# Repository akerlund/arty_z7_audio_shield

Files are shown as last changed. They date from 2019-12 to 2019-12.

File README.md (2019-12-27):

# arty_z7_audio_shield

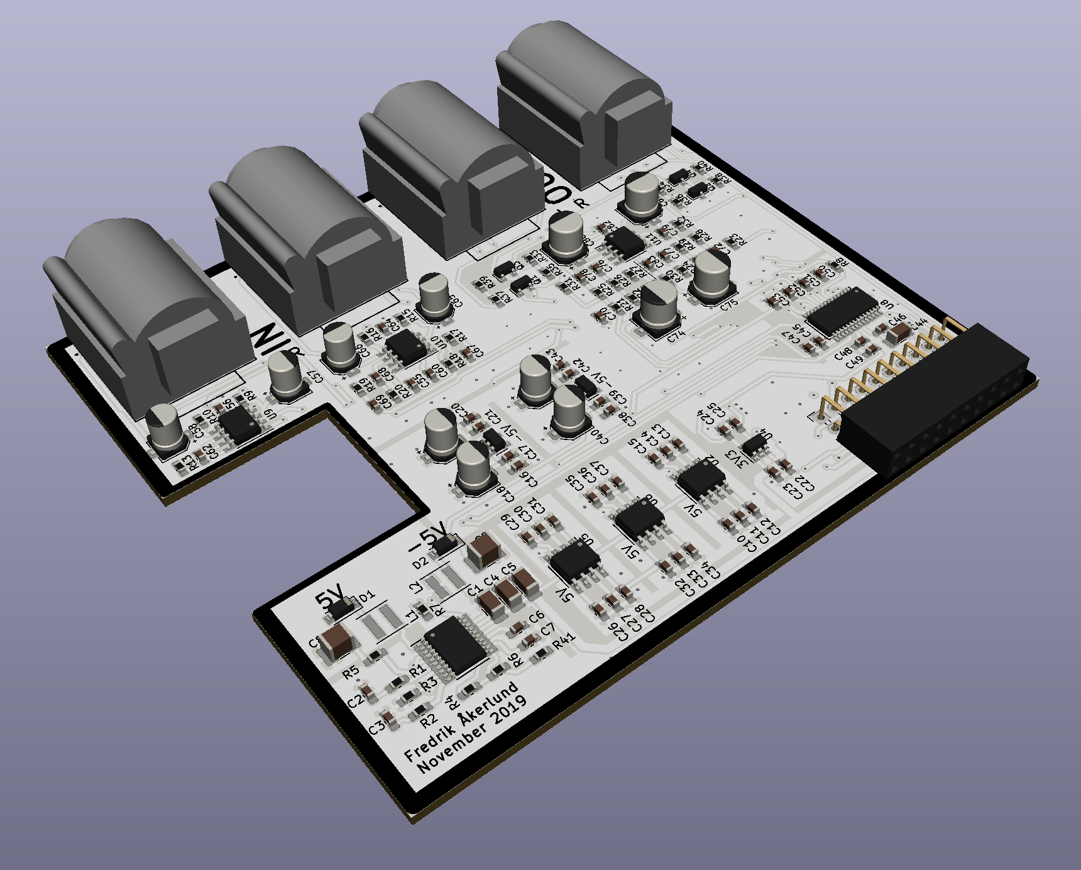
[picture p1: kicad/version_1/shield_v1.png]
The Shield


Stereo audio IF with a Cirrus CS4272 24-bit codec IC.
Designed to be placed as a shield on the Arty Z7 FPGA board.
Has a 20-pin connector for the "mixer interface", i.e., a PCB with sliders and encoders.

First test (verison1) failed, the +-5V booster (bottom left in pic) operates incorrecty and
eats a lot of current, causing the 3.3V supply down to 0.8V.

Forgot the exposed thermal pad under that IC, too. Fixed with some copper tape, but might correlate?

Next step is to try a new design, i.e., another booster.

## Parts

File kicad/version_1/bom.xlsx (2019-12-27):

Ref | Qnty |  | Value | Part | Footprint | Description | Vendor
C1, C4 | 2 |  | 3.3uF | Device:C | Capacitor_SMD:C_0603_1608Metric_Pad1.05x0.95mm_HandSolder | Unpolarized capacitor
C2, C3 | 2 |  | 47nF | Device:C | Capacitor_SMD:C_0603_1608Metric_Pad1.05x0.95mm_HandSolder | Unpolarized capacitor
C5 | 1 |  | 5.6uF | Device:C | Capacitor_SMD:C_0603_1608Metric_Pad1.05x0.95mm_HandSolder | Unpolarized capacitor
C6, C7, C11, C14, C22, C24, C25, C27, C30, C33, C36, C45, C47, C48, C50, C53 | 16 |  | 1uF | Device:C | Capacitor_SMD:C_0603_1608Metric_Pad1.05x0.95mm_HandSolder | Unpolarized capacitor
C8, C9 | 2 |  | 10uF | Device:C | Capacitor_SMD:C_1210_3225Metric_Pad1.42x2.65mm_HandSolder | Unpolarized capacitor
C10, C13, C16, C21, C23, C26, C29, C32, C35, C38, C43 | 11 |  | 100nF | Device:C | Capacitor_SMD:C_0603_1608Metric_Pad1.05x0.95mm_HandSolder | Unpolarized capacitor
C12, C15, C28, C31, C34, C37 | 6 |  | 2.2uF | Device:C | Capacitor_SMD:C_0603_1608Metric_Pad1.05x0.95mm_HandSolder | Unpolarized capacitor
C17, C20, C39, C42 | 4 |  | 1nF | Device:C | Capacitor_SMD:C_0603_1608Metric_Pad1.05x0.95mm_HandSolder | Unpolarized capacitor
C18, C19, C40, C41 | 4 |  | 2.2uF | Device:CP_Small | Capacitor_SMD:CP_Elec_4x5.7 | Polarized capacitor, small symbol
C44 | 1 |  | 47uF | Device:C | Capacitor_SMD:C_1206_3216Metric_Pad1.42x1.75mm_HandSolder | Unpolarized capacitor
C46, C49, C51, C52 | 4 |  | 0.1uF | Device:C | Capacitor_SMD:C_0603_1608Metric_Pad1.05x0.95mm_HandSolder | Unpolarized capacitor
C54, C55, C59, C60, C82, C83 | 6 |  | 2.2uF | Device:C | Capacitor_SMD:C_0603_1608Metric_Pad1.05x0.95mm_HandSolder | Unpolarized capacitor
C56, C64 | 2 | C0G | 0.01uF | Device:C | Capacitor_SMD:C_0603_1608Metric_Pad1.05x0.95mm_HandSolder | Unpolarized capacitor
C57, C58, C65, C66 | 4 |  | 10uF | Device:CP_Small | Capacitor_SMD:CP_Elec_4x5.7 | Polarized capacitor, small symbol
C61, C62, C67, C68, C78, C79 | 6 | C0G | 470pF | Device:C | Capacitor_SMD:C_0603_1608Metric_Pad1.05x0.95mm_HandSolder | Unpolarized capacitor
C63, C69 | 2 | C0G | 2.7nF | Device:C | Capacitor_SMD:C_0603_1608Metric_Pad1.05x0.95mm_HandSolder | Unpolarized capacitor
C70, C72 | 2 | C0G | 2.2nF | Device:C | Capacitor_SMD:C_0603_1608Metric_Pad1.05x0.95mm_HandSolder | Unpolarized capacitor
C71, C73 | 2 | C0G | 6.8nF | Device:C | Capacitor_SMD:C_0603_1608Metric_Pad1.05x0.95mm_HandSolder | Unpolarized capacitor
C74, C75 | 2 |  | 22uF | Device:C | Capacitor_SMD:CP_Elec_5x5.7 | Unpolarized capacitor
C76, C77 | 2 | C0G | 1.5nF | Device:C | Capacitor_SMD:C_0603_1608Metric_Pad1.05x0.95mm_HandSolder | Unpolarized capacitor
C80, C81 | 2 |  | 22uF | Device:CP_Small | Capacitor_SMD:CP_Elec_5x5.7 | Polarized capacitor, small symbol
D1, D2 | 2 |  | SCH | Device:D_Schottky | Diode_SMD:D_SOD-123 | Schottky diode
J1 | 1 |  | Conn_02x10_Odd_Even | Connector_Generic:Conn_02x10_Odd_Even | Connector_PinSocket_2.54mm:PinSocket_2x10_P2.54mm_Horizontal | Generic connector, double row, 02x10, odd/even pin numbering scheme (row 1 odd numbers, row 2 even numbers), script generated (kicad-library-utils/schlib/autogen/connector/)
J2 | 1 |  | IN_LEFT | SamacSys_Parts:NMJ4HCD2 | SamacSys_Parts:NMJ4HCD2 | Phone Connectors 2C MONO 2-SPST NC
J3 | 1 |  | OUT_LEFT | SamacSys_Parts:NMJ4HCD2 | SamacSys_Parts:NMJ4HCD2 | Phone Connectors 2C MONO 2-SPST NC
J4 | 1 |  | IN_RIGHT | SamacSys_Parts:NMJ4HCD2 | SamacSys_Parts:NMJ4HCD2 | Phone Connectors 2C MONO 2-SPST NC
J5 | 1 |  | OUT_RIGHT | SamacSys_Parts:NMJ4HCD2 | SamacSys_Parts:NMJ4HCD2 | Phone Connectors 2C MONO 2-SPST NC
L1 | 1 |  | 2.2uH | Device:L_Small | Inductor_SMD:L_Coilcraft_XxL4020 | Inductor, small symbol
L2 | 1 |  | 3.3uH | Device:L_Small | Inductor_SMD:L_Coilcraft_XxL4030 | Inductor, small symbol
Q1, Q2, Q3, Q4 | 4 |  | PNP_BEC | Device:Q_PNP_BEC | Package_TO_SOT_SMD:SOT-23 | PNP transistor, base/emitter/collector
R1 | 1 |  | 4.7k | Device:R | Resistor_SMD:R_0603_1608Metric_Pad1.05x0.95mm_HandSolder | Resistor
R2 | 1 |  | 8.2k | Device:R | Resistor_SMD:R_0603_1608Metric_Pad1.05x0.95mm_HandSolder | Resistor
R3 | 1 |  | 268k | Device:R | Resistor_SMD:R_0603_1608Metric_Pad1.05x0.95mm_HandSolder | Resistor
R4 | 1 |  | 158k | Device:R | Resistor_SMD:R_0603_1608Metric_Pad1.05x0.95mm_HandSolder | Resistor
R5 | 1 |  | 604k | Device:R | Resistor_SMD:R_0603_1608Metric_Pad1.05x0.95mm_HandSolder | Resistor
R6 | 1 |  | 1.15M | Device:R | Resistor_SMD:R_0603_1608Metric_Pad1.05x0.95mm_HandSolder | Resistor
R7 | 1 |  | 115k | Device:R | Resistor_SMD:R_0603_1608Metric_Pad1.05x0.95mm_HandSolder | Resistor
R8, R35, R36 | 3 |  | 47k | Device:R | Resistor_SMD:R_0603_1608Metric_Pad1.05x0.95mm_HandSolder | Resistor
R9, R10, R15, R16, R37, R38 | 6 |  | 10k | Device:R | Resistor_SMD:R_0603_1608Metric_Pad1.05x0.95mm_HandSolder | Resistor
R11, R13, R17, R19 | 4 |  | 634R | Device:R | Resistor_SMD:R_0603_1608Metric_Pad1.05x0.95mm_HandSolder | Resistor
R12, R14, R18, R20 | 4 |  | 91R | Device:R | Resistor_SMD:R_0603_1608Metric_Pad1.05x0.95mm_HandSolder | Resistor
R21, R23 | 2 |  | 4.42k | Device:R | Resistor_SMD:R_0603_1608Metric_Pad1.05x0.95mm_HandSolder | Resistor
R22, R24 | 2 |  | 1.33k | Device:R | Resistor_SMD:R_0603_1608Metric_Pad1.05x0.95mm_HandSolder | Resistor
R25, R28 | 2 |  | 2.32k | Device:R | Resistor_SMD:R_0603_1608Metric_Pad1.05x0.95mm_HandSolder | Resistor
R26, R29 | 2 |  | 715R | Device:R | Resistor_SMD:R_0603_1608Metric_Pad1.05x0.95mm_HandSolder | Resistor
R27, R30 | 2 |  | 1.5k | Device:R | Resistor_SMD:R_0603_1608Metric_Pad1.05x0.95mm_HandSolder | Resistor
R31, R32 | 2 |  | 4.99k | Device:R | Resistor_SMD:R_0603_1608Metric_Pad1.05x0.95mm_HandSolder | Resistor
R33, R34 | 2 |  | 560R | Device:R | Resistor_SMD:R_0603_1608Metric_Pad1.05x0.95mm_HandSolder | Resistor
R39, R40 | 2 |  | 2k | Device:R | Resistor_SMD:R_0603_1608Metric_Pad1.05x0.95mm_HandSolder | Resistor
U1 | 1 |  | ADP5071 | freakuency:ADP5071 | Package_SO:TSSOP-20_4.4x6.5mm_P0.65mm
U2, U5, U6 | 3 |  | ADP7118 | freakuency:ADP7118 | Package_SO:SOIC-8_3.9x4.9mm_P1.27mm
U3, U7 | 2 |  | ADP7182 | freakuency:ADP7182 | Package_TO_SOT_SMD:SOT-23-5
U4 | 1 |  | MIC5211 | freakuency:MIC5211 | Package_TO_SOT_SMD:SOT-23-6
U8 | 1 |  | CS4272 | freakuency:CS4272 | Package_SO:TSSOP-28_4.4x9.7mm_P0.65mm
U9, U10, U11 | 3 |  | MC33078 | freakuency:MC33078 | Package_SO:SOIC-8_3.9x4.9mm_P1.27mm
U12 | 1 |  | chip_kit | freakuency:chip_kit | f_library:chipKIT

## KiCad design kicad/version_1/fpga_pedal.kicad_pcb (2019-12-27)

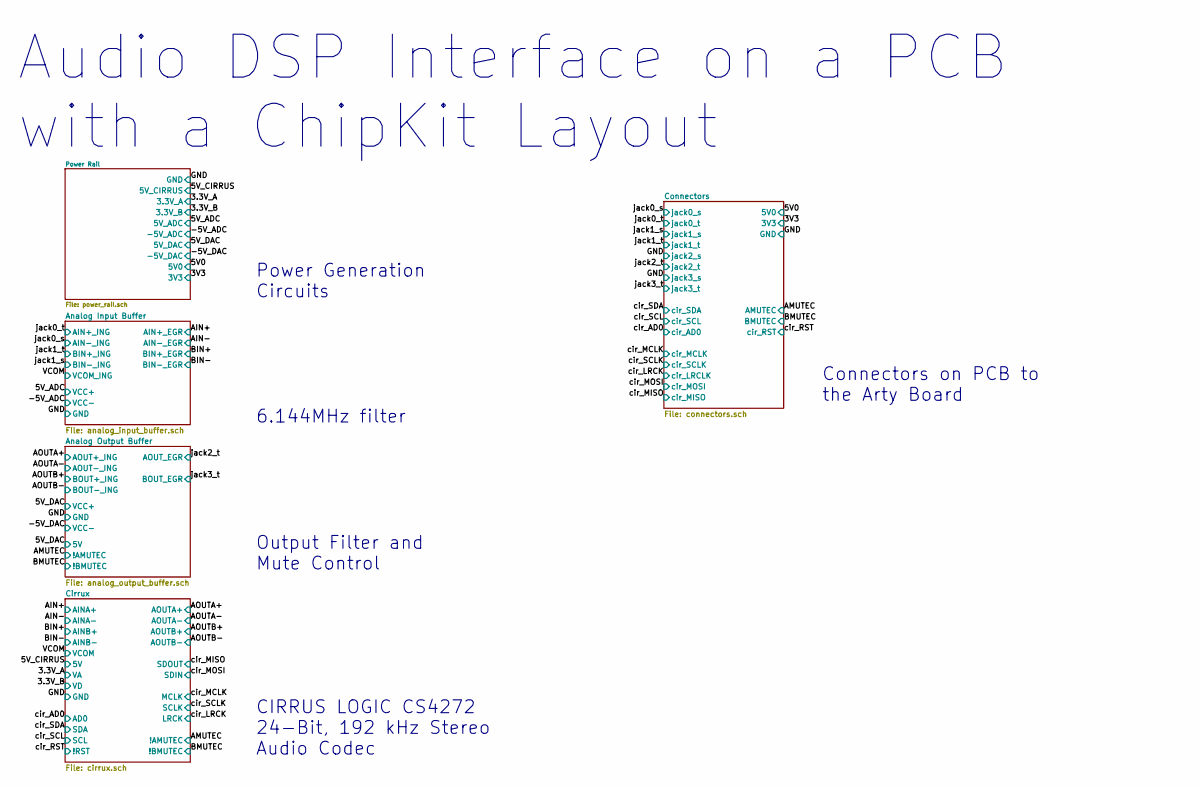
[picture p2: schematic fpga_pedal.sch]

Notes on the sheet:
CIRRUS LOGIC CS4272 24-Bit, 192 kHz Stereo Audio Codec
6.144MHz filter
Output Filter and Mute Control
Power Generation Circuits
Connectors on PCB to the Arty Board
Audio DSP Interface on a PCB with a ChipKit Layout

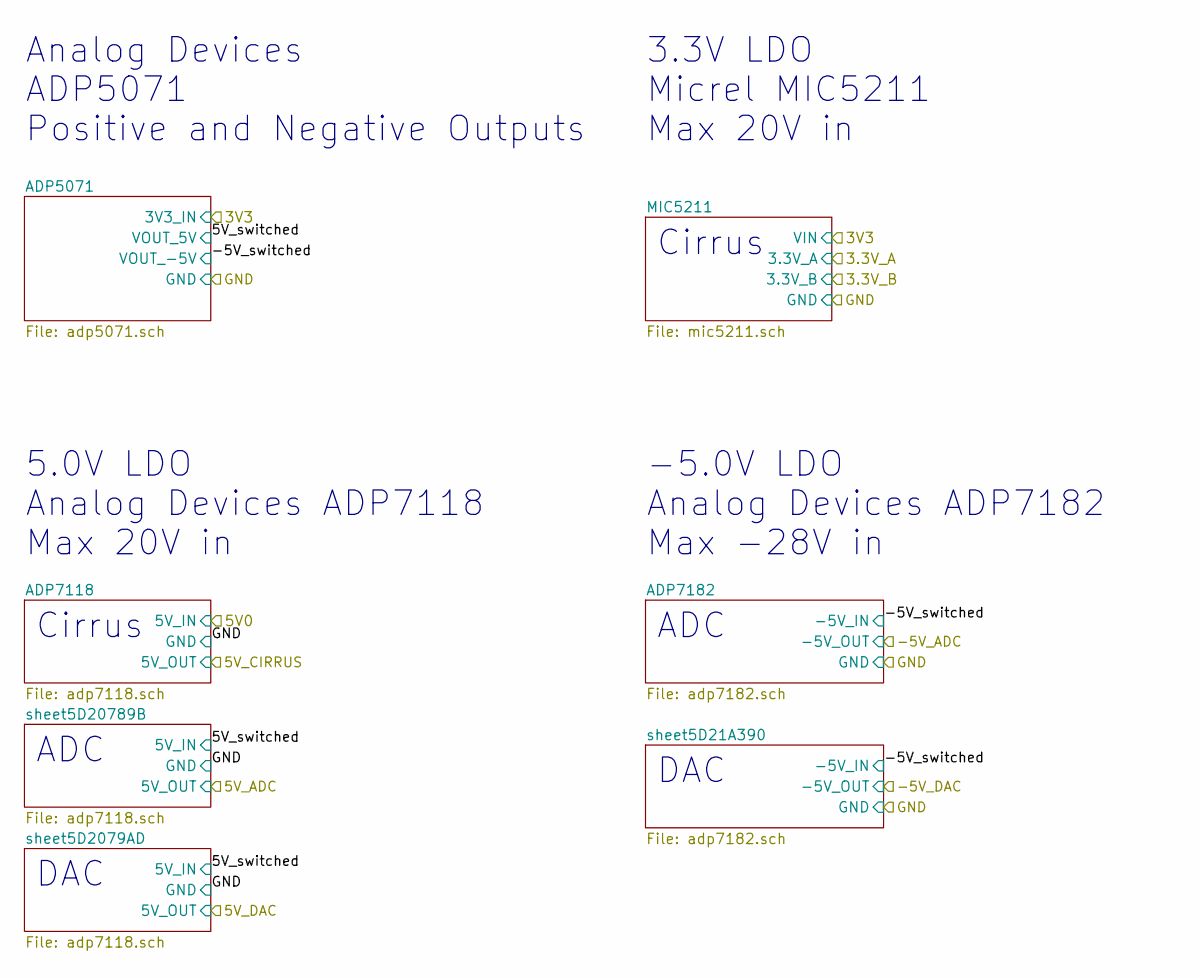
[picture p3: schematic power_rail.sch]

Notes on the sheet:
3.3V LDO Micrel MIC5211 Max 20V in
5.0V LDO Analog Devices ADP7118 Max 20V in
-5.0V LDO Analog Devices ADP7182 Max -28V in
Analog Devices ADP5071 Positive and Negative Outputs
ADC
Cirrus
DAC

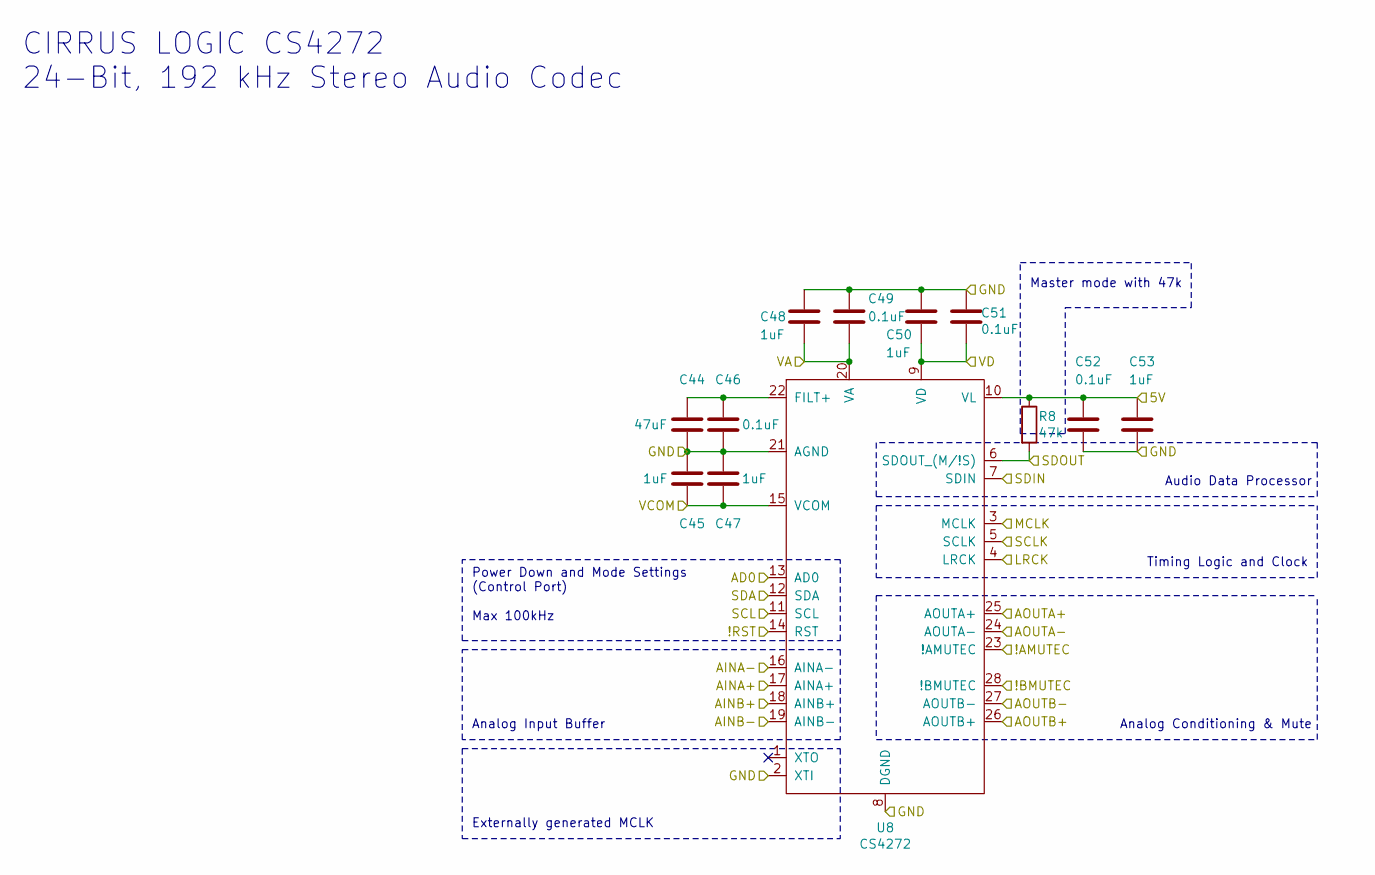
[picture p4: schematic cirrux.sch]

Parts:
C44: 47uF; C_1206_3216Metric_Pad1.42x1.75mm_HandSolder
C45, C47, C48, C50, C53: 1uF; C_0603_1608Metric_Pad1.05x0.95mm_HandSolder
C46, C49, C51, C52: 0.1uF; C_0603_1608Metric_Pad1.05x0.95mm_HandSolder
R8: 47k; R_0603_1608Metric_Pad1.05x0.95mm_HandSolder
U8: CS4272; TSSOP-28_4.4x9.7mm_P0.65mm

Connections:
/3.3V_A: C48.2, C49.2, U8.20 (VA); also elsewhere on the board
/3.3V_B: C50.2, C51.2, U8.9 (VD); also elsewhere on the board
/5V_CIRRUS: C52.1, C53.1, R8.1, U8.10 (VL); also elsewhere on the board
/AIN+: U8.17 (AINA+); also elsewhere on the board
/AIN-: U8.16 (AINA-); also elsewhere on the board
/AMUTEC: U8.23 (!AMUTEC); also elsewhere on the board
/AOUTA+: U8.25 (AOUTA+); also elsewhere on the board
/AOUTA-: U8.24 (AOUTA-); also elsewhere on the board
/AOUTB+: U8.26 (AOUTB+); also elsewhere on the board
/AOUTB-: U8.27 (AOUTB-); also elsewhere on the board
/BIN+: U8.18 (AINB+); also elsewhere on the board
/BIN-: U8.19 (AINB-); also elsewhere on the board
/BMUTEC: U8.28 (!BMUTEC); also elsewhere on the board
/GND: C44.2, C45.1, C46.2, C47.1, C48.1, C49.1, C50.1, C51.1, C52.2, C53.2, U8.2 (XTI), U8.8 (DGND), U8.21 (AGND); also elsewhere on the board
/VCOM: C45.2, C47.2, U8.15 (VCOM); also elsewhere on the board
/cir_AD0: U8.13 (AD0); also elsewhere on the board
/cir_LRCK: U8.4 (LRCK); also elsewhere on the board
/cir_MCLK: U8.3 (MCLK); also elsewhere on the board
/cir_MISO: R8.2, U8.6 (SDOUT_(M/!S)); also elsewhere on the board
/cir_MOSI: U8.7 (SDIN); also elsewhere on the board
/cir_RST: U8.14 (RST); also elsewhere on the board
/cir_SCL: U8.11 (SCL); also elsewhere on the board
/cir_SCLK: U8.5 (SCLK); also elsewhere on the board
/cir_SDA: U8.12 (SDA); also elsewhere on the board
unnamed: C44.1, C46.1, U8.22 (FILT+)

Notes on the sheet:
Analog Input Buffer
Power Down and Mode Settings (Control Port) Max 100kHz
Analog Conditioning & Mute
Timing Logic and Clock
Audio Data Processor
Master mode with 47k
Externally generated MCLK
CIRRUS LOGIC CS4272 24-Bit, 192 kHz Stereo Audio Codec

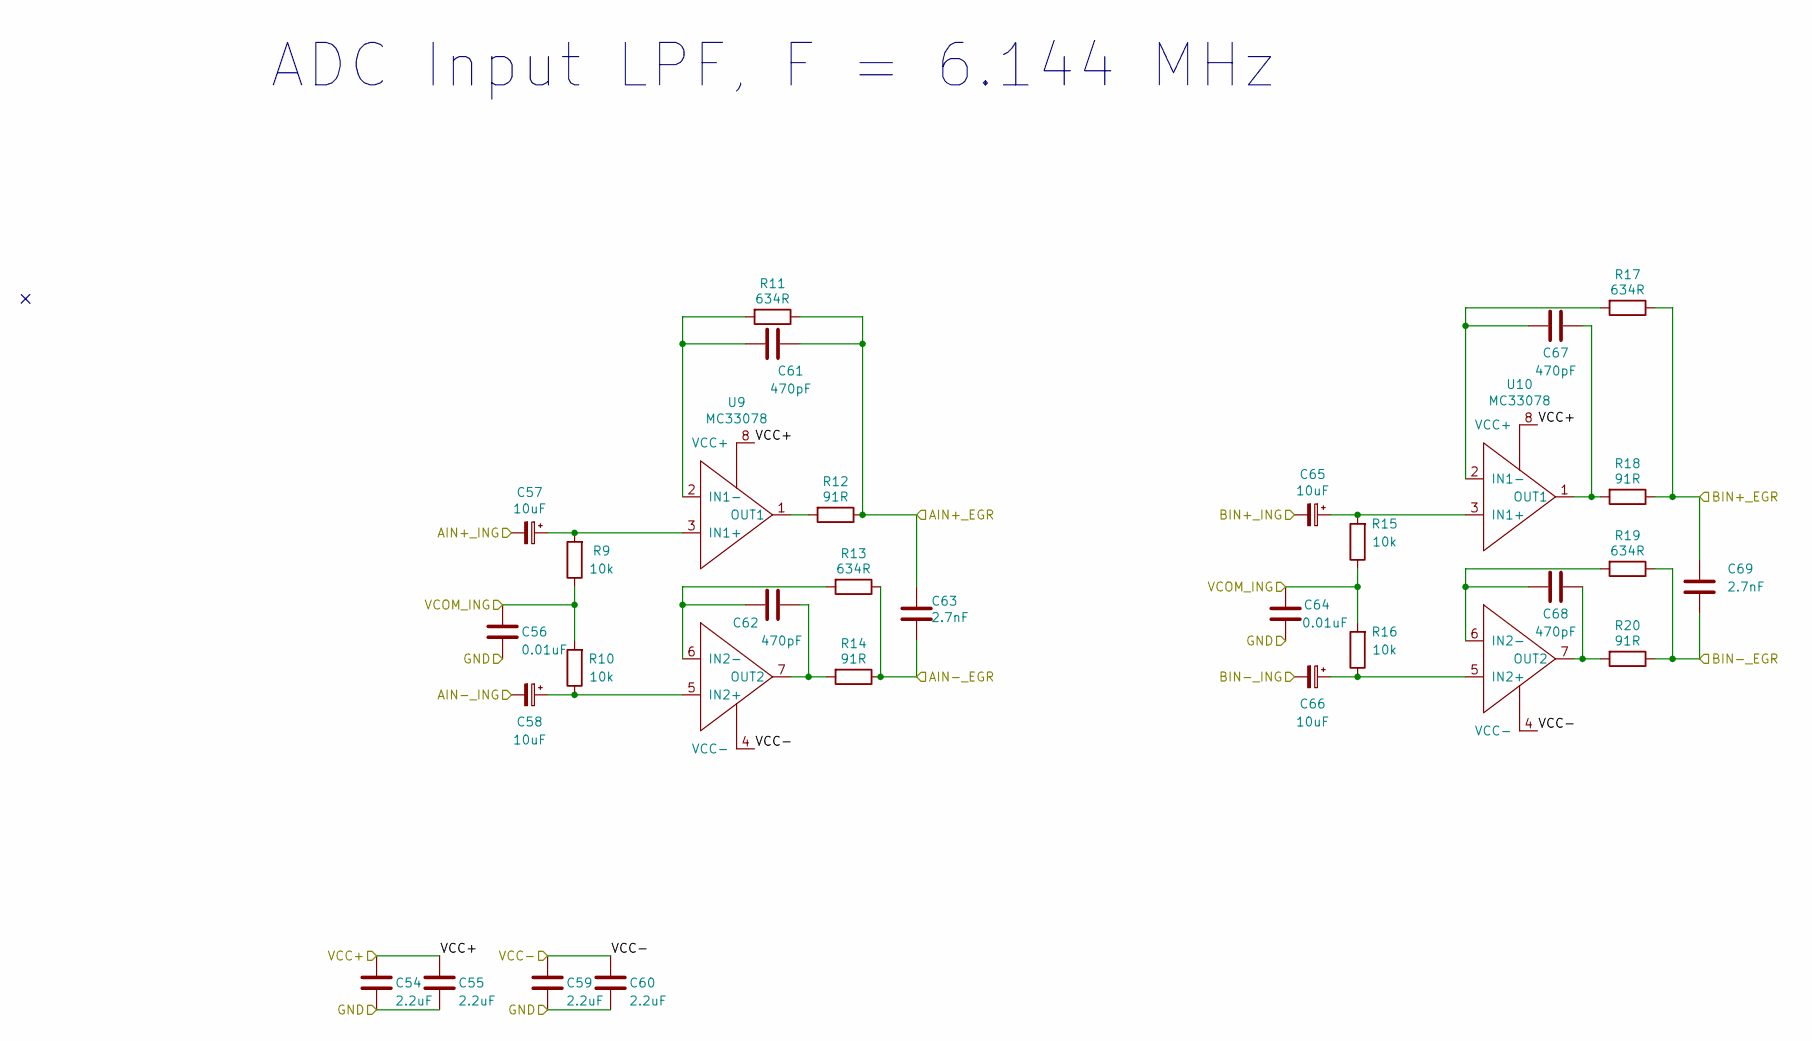
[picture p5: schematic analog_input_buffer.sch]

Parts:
C54, C55, C59, C60: 2.2uF; C_0603_1608Metric_Pad1.05x0.95mm_HandSolder
C56, C64: 0.01uF; C_0603_1608Metric_Pad1.05x0.95mm_HandSolder
C57, C58, C65, C66: 10uF; CP_Elec_4x5.7
C61, C62, C67, C68: 470pF; C_0603_1608Metric_Pad1.05x0.95mm_HandSolder
C63, C69: 2.7nF; C_0603_1608Metric_Pad1.05x0.95mm_HandSolder
R9, R10, R15, R16: 10k; R_0603_1608Metric_Pad1.05x0.95mm_HandSolder
R11, R13, R17, R19: 634R; R_0603_1608Metric_Pad1.05x0.95mm_HandSolder
R12, R14, R18, R20: 91R; R_0603_1608Metric_Pad1.05x0.95mm_HandSolder
U9, U10: MC33078; SOIC-8_3.9x4.9mm_P1.27mm

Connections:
/5V_ADC: C54.2, C55.2, U9.8 (VCC+), U10.8 (VCC+); also elsewhere on the board
/-5V_ADC: C59.2, C60.2, U9.4 (VCC-), U10.4 (VCC-); also elsewhere on the board
/AIN+: C61.1, C63.2, R11.1, R12.1; also elsewhere on the board
/AIN-: C63.1, R13.1, R14.1; also elsewhere on the board
/BIN+: C69.2, R17.1, R18.1; also elsewhere on the board
/BIN-: C69.1, R19.1, R20.1; also elsewhere on the board
/GND: C54.1, C55.1, C56.1, C59.1, C60.1, C64.1; also elsewhere on the board
/VCOM: C56.2, C64.2, R9.1, R10.2, R15.1, R16.2; also elsewhere on the board
/jack0_s: C58.2; also elsewhere on the board
/jack0_t: C57.2; also elsewhere on the board
/jack1_s: C66.2; also elsewhere on the board
/jack1_t: C65.2; also elsewhere on the board
unnamed: C57.1, R9.2, U9.3 (IN1+)
unnamed: C58.1, R10.1, U9.5 (IN2+)
unnamed: C61.2, R11.2, U9.2 (IN1-)
unnamed: C62.1, R14.2, U9.7 (OUT2)
unnamed: C62.2, R13.2, U9.6 (IN2-)
unnamed: C65.1, R15.2, U10.3 (IN1+)
unnamed: C66.1, R16.1, U10.5 (IN2+)
unnamed: C67.1, R18.2, U10.1 (OUT1)
unnamed: C67.2, R17.2, U10.2 (IN1-)
unnamed: C68.1, R20.2, U10.7 (OUT2)
unnamed: C68.2, R19.2, U10.6 (IN2-)
unnamed: R12.2, U9.1 (OUT1)

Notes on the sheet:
ADC Input LPF, F = 6.144 MHz

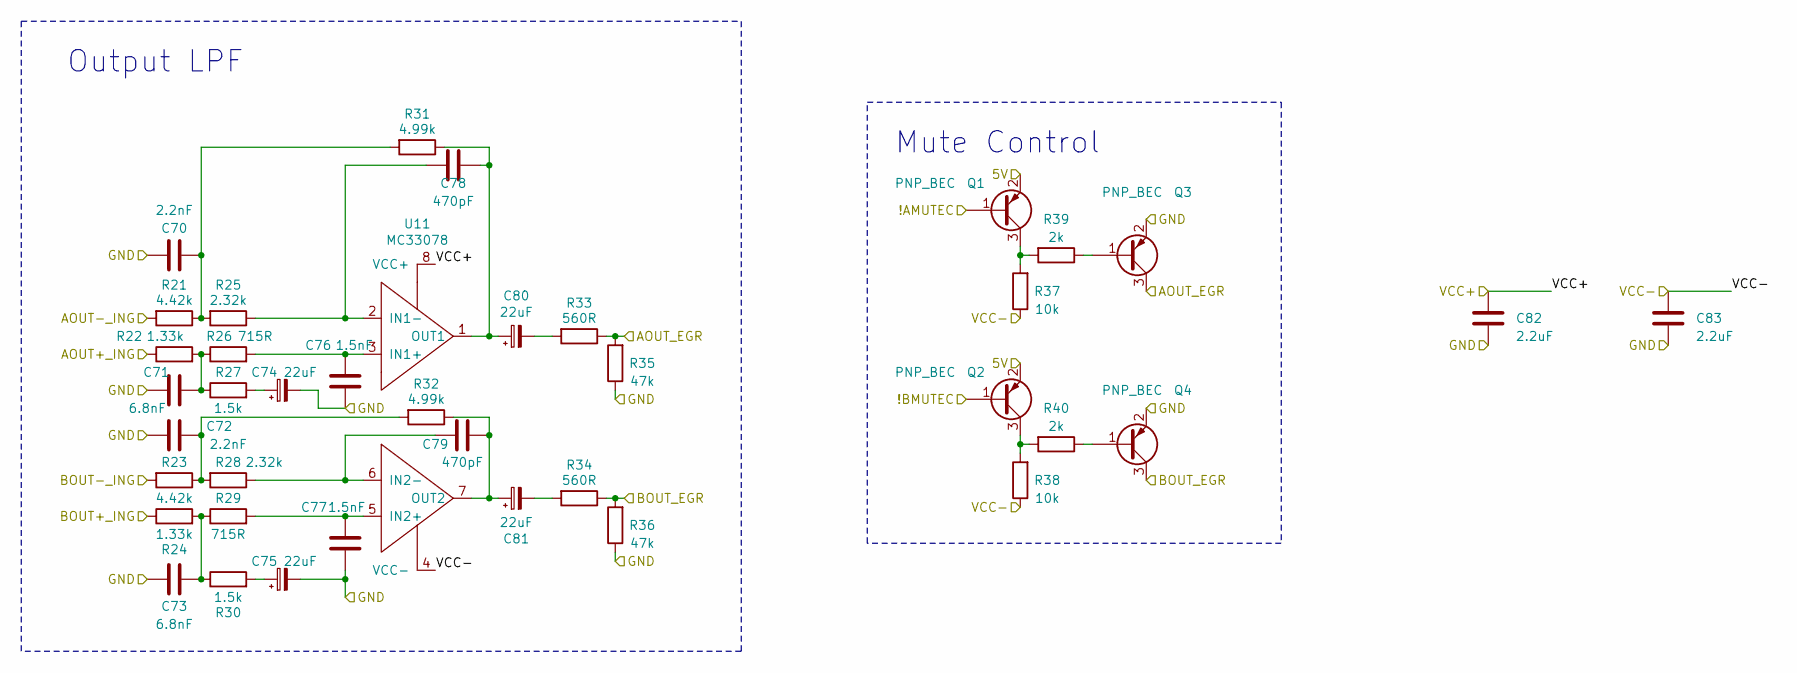
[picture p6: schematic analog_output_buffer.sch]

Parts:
C70, C72: 2.2nF; C_0603_1608Metric_Pad1.05x0.95mm_HandSolder
C71, C73: 6.8nF; C_0603_1608Metric_Pad1.05x0.95mm_HandSolder
C74, C75, C80, C81: 22uF; CP_Elec_5x5.7
C76, C77: 1.5nF; C_0603_1608Metric_Pad1.05x0.95mm_HandSolder
C78, C79: 470pF; C_0603_1608Metric_Pad1.05x0.95mm_HandSolder
C82, C83: 2.2uF; C_0603_1608Metric_Pad1.05x0.95mm_HandSolder
Q1, Q2, Q3, Q4: PNP_BEC; SOT-23
R21, R23: 4.42k; R_0603_1608Metric_Pad1.05x0.95mm_HandSolder
R22, R24: 1.33k; R_0603_1608Metric_Pad1.05x0.95mm_HandSolder
R25, R28: 2.32k; R_0603_1608Metric_Pad1.05x0.95mm_HandSolder
R26, R29: 715R; R_0603_1608Metric_Pad1.05x0.95mm_HandSolder
R27, R30: 1.5k; R_0603_1608Metric_Pad1.05x0.95mm_HandSolder
R31, R32: 4.99k; R_0603_1608Metric_Pad1.05x0.95mm_HandSolder
R33, R34: 560R; R_0603_1608Metric_Pad1.05x0.95mm_HandSolder
R35, R36: 47k; R_0603_1608Metric_Pad1.05x0.95mm_HandSolder
R37, R38: 10k; R_0603_1608Metric_Pad1.05x0.95mm_HandSolder
R39, R40: 2k; R_0603_1608Metric_Pad1.05x0.95mm_HandSolder
U11: MC33078; SOIC-8_3.9x4.9mm_P1.27mm

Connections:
/5V_DAC: C82.2, Q1.2 (E), Q2.2 (E), U11.8 (VCC+); also elsewhere on the board
/-5V_DAC: C83.2, R37.1, R38.1, U11.4 (VCC-); also elsewhere on the board
/AMUTEC: Q1.1 (B); also elsewhere on the board
/AOUTA+: R22.1; also elsewhere on the board
/AOUTA-: R21.2; also elsewhere on the board
/AOUTB+: R24.1; also elsewhere on the board
/AOUTB-: R23.2; also elsewhere on the board
/BMUTEC: Q2.1 (B); also elsewhere on the board
/GND: C70.1, C71.2, C72.1, C73.2, C74.2, C75.2, C76.2, C77.1, C82.1, C83.1, Q3.2 (E), Q4.2 (E), R35.1, R36.1; also elsewhere on the board
/jack2_t: Q3.3 (C), R33.1, R35.2; also elsewhere on the board
/jack3_t: Q4.3 (C), R34.1, R36.2; also elsewhere on the board
unnamed: C70.2, R21.1, R25.2, R31.2
unnamed: C71.1, R22.2, R26.1, R27.1
unnamed: C72.2, R23.1, R28.2, R32.2
unnamed: C73.1, R24.2, R29.1, R30.1
unnamed: C74.1, R27.2
unnamed: C75.1, R30.2
unnamed: C76.1, R26.2, U11.3 (IN1+)
unnamed: C77.2, R29.2, U11.5 (IN2+)
unnamed: C78.1, C80.1, R31.1, U11.1 (OUT1)
unnamed: C78.2, R25.1, U11.2 (IN1-)
unnamed: C79.1, C81.1, R32.1, U11.7 (OUT2)
unnamed: C79.2, R28.1, U11.6 (IN2-)
unnamed: C80.2, R33.2
unnamed: C81.2, R34.2
unnamed: Q1.3 (C), R37.2, R39.2
unnamed: Q2.3 (C), R38.2, R40.2
unnamed: Q3.1 (B), R39.1
unnamed: Q4.1 (B), R40.1

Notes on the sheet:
Mute Control
Output LPF

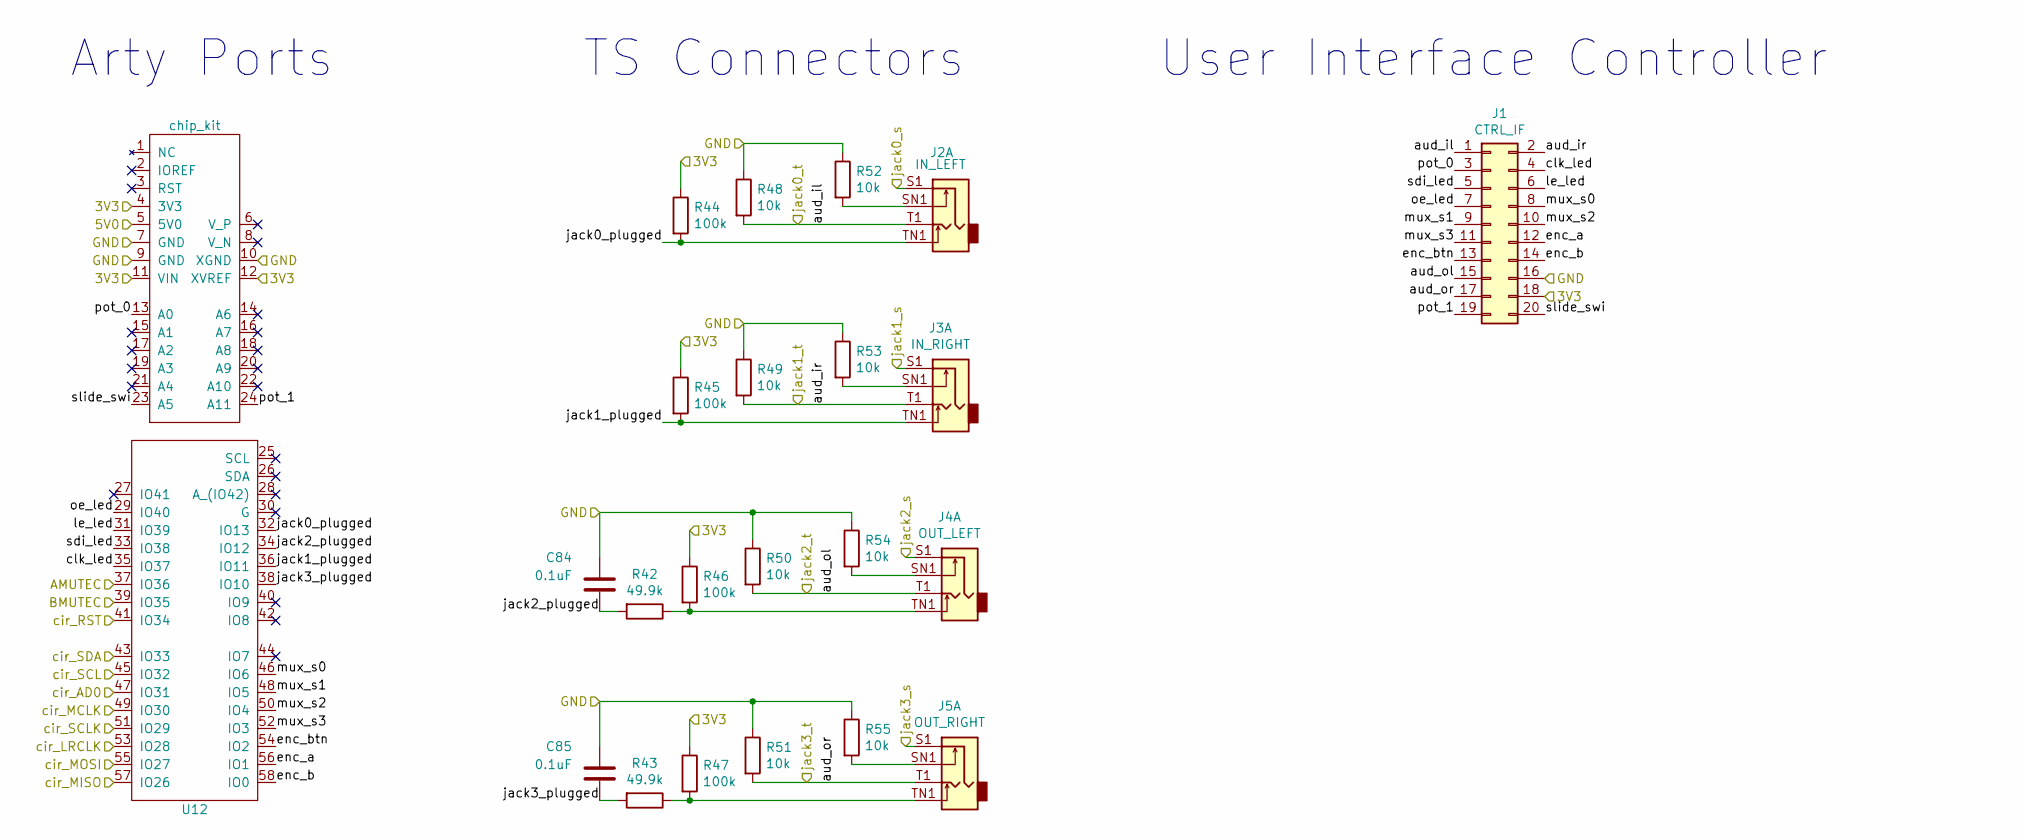
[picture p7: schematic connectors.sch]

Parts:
C84, C85: 0.1uF; C_0603_1608Metric_Pad1.05x0.95mm_HandSolder
J1: CTRL_IF; PinSocket_2x10_P2.54mm_Horizontal
J2: IN_LEFT; con_pcb_jack_mono_sw_6_3mm
J3: IN_RIGHT; con_pcb_jack_mono_sw_6_3mm
J4: OUT_LEFT; con_pcb_jack_mono_sw_6_3mm
J5: OUT_RIGHT; con_pcb_jack_mono_sw_6_3mm
R42, R43: 49.9k; R_0603_1608Metric_Pad1.05x0.95mm_HandSolder
R44, R45, R46, R47: 100k; R_0603_1608Metric_Pad1.05x0.95mm_HandSolder
R48, R49, R50, R51, R52, R53, R54, R55: 10k; R_0603_1608Metric_Pad1.05x0.95mm_HandSolder
U12: chip_kit; chipKIT

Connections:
/3V3: J1.18, R44.1, R45.1, R46.1, R47.1, U12.4 (3V3), U12.11 (VIN), U12.12 (XVREF); also elsewhere on the board
/5V0: U12.5 (5V0); also elsewhere on the board
/AMUTEC: U12.37 (IO36); also elsewhere on the board
/BMUTEC: U12.39 (IO35); also elsewhere on the board
/Connectors/clk_led: J1.4, U12.35 (IO37)
/Connectors/enc_a: J1.12, U12.56 (IO1)
/Connectors/enc_b: J1.14, U12.58 (IO0)
/Connectors/enc_btn: J1.13, U12.54 (IO2)
/Connectors/jack0_plugged: J2.TN1, R44.2, U12.32 (IO13)
/Connectors/jack1_plugged: J3.TN1, R45.2, U12.36 (IO11)
/Connectors/jack2_plugged: C84.2, R42.2, U12.34 (IO12)
/Connectors/jack3_plugged: C85.2, R43.2, U12.38 (IO10)
/Connectors/le_led: J1.6, U12.31 (IO39)
/Connectors/mux_s0: J1.8, U12.46 (IO6)
/Connectors/mux_s1: J1.9, U12.48 (IO5)
/Connectors/mux_s2: J1.10, U12.50 (IO4)
/Connectors/mux_s3: J1.11, U12.52 (IO3)
/Connectors/oe_led: J1.7, U12.29 (IO40)
/Connectors/pot_0: J1.3, U12.13 (A0)
/Connectors/pot_1: J1.19, U12.24 (A11)
/Connectors/sdi_led: J1.5, U12.33 (IO38)
/Connectors/slide_swi: J1.20, U12.23 (A5)
/GND: C84.1, C85.1, J1.16, J4.S1, J5.S1, R48.1, R49.1, R50.1, R51.1, R52.1, R53.1, R54.1, R55.1, U12.7 (GND), U12.9 (GND), U12.10 (XGND); also elsewhere on the board
/cir_AD0: U12.47 (IO31); also elsewhere on the board
/cir_LRCK: U12.53 (IO28); also elsewhere on the board
/cir_MCLK: U12.49 (IO30); also elsewhere on the board
/cir_MISO: U12.57 (IO26); also elsewhere on the board
/cir_MOSI: U12.55 (IO27); also elsewhere on the board
/cir_RST: U12.41 (IO34); also elsewhere on the board
/cir_SCL: U12.45 (IO32); also elsewhere on the board
/cir_SCLK: U12.51 (IO29); also elsewhere on the board
/cir_SDA: U12.43 (IO33); also elsewhere on the board
/jack0_s: J2.S1; also elsewhere on the board
/jack0_t: J1.1, J2.T1, R48.2; also elsewhere on the board
/jack1_s: J3.S1; also elsewhere on the board
/jack1_t: J1.2, J3.T1, R49.2; also elsewhere on the board
/jack2_t: J1.15, J4.T1, R50.2; also elsewhere on the board
/jack3_t: J1.17, J5.T1, R51.2; also elsewhere on the board
unnamed: J2.SN1, R52.2
unnamed: J3.SN1, R53.2
unnamed: J4.SN1, R54.2
unnamed: J4.TN1, R42.1, R46.2
unnamed: J5.SN1, R55.2
unnamed: J5.TN1, R43.1, R47.2

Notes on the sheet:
Arty Ports
TS Connectors
User Interface Controller

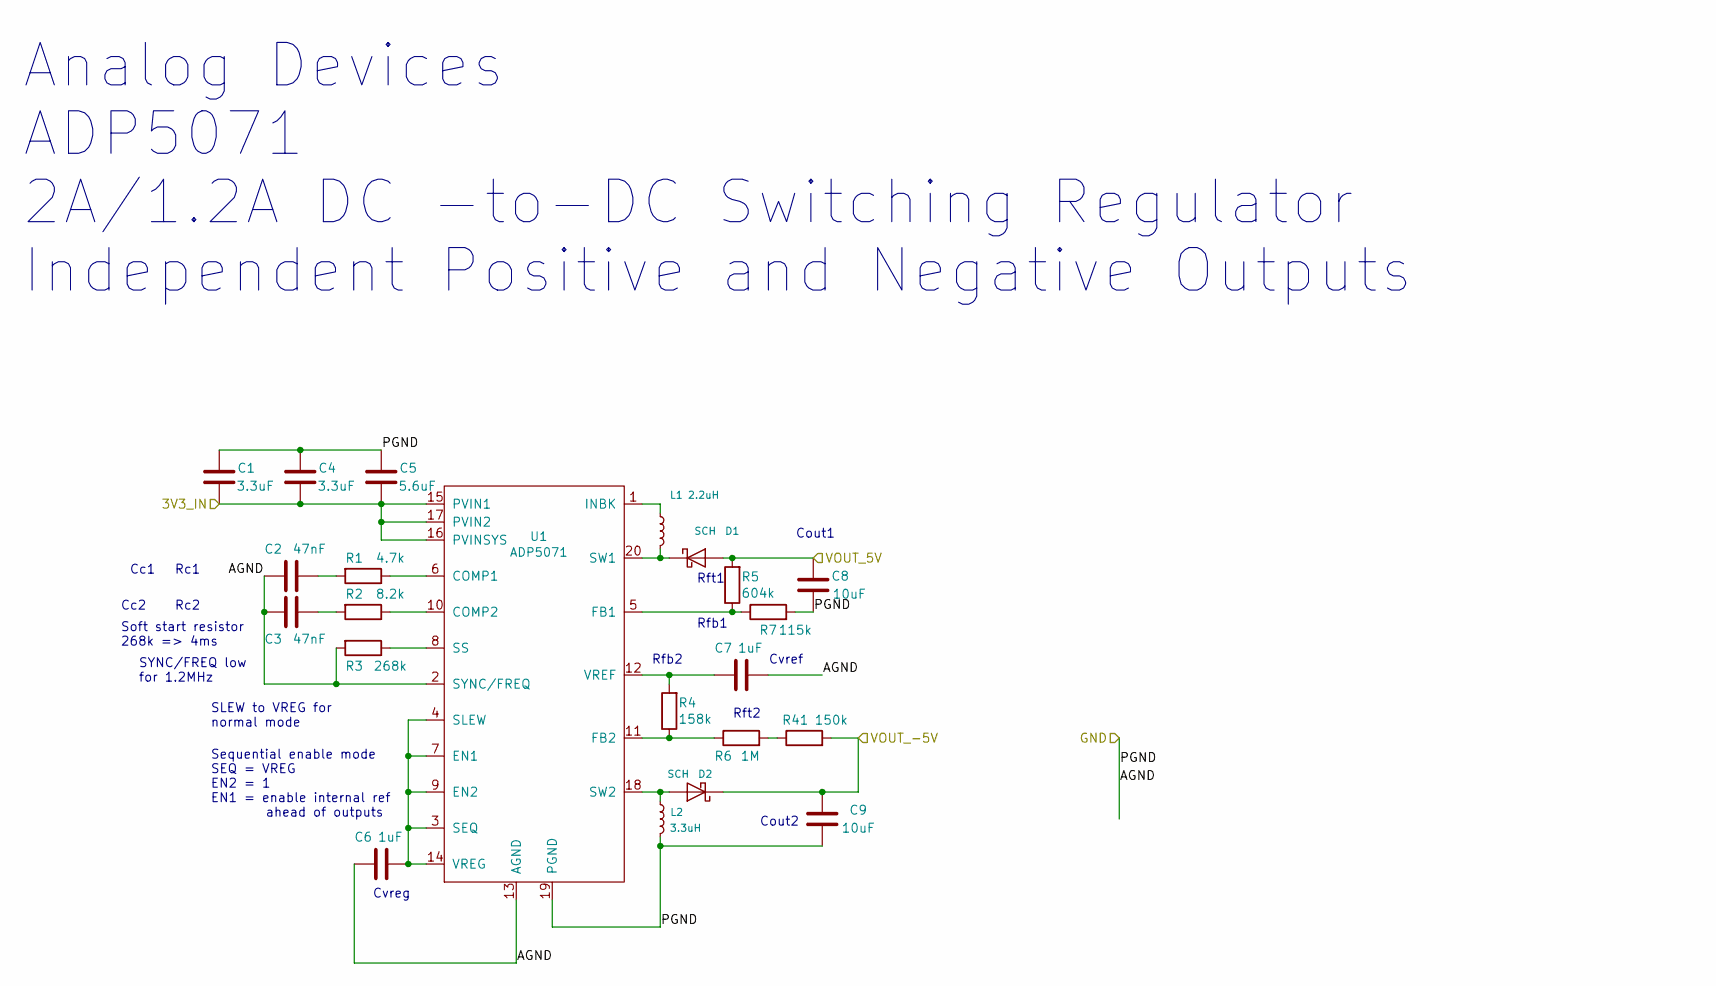
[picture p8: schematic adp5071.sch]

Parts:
C1, C4: 3.3uF; C_1206_3216Metric_Pad1.42x1.75mm_HandSolder
C2, C3: 47nF; C_0603_1608Metric_Pad1.05x0.95mm_HandSolder
C5: 5.6uF; C_1206_3216Metric_Pad1.42x1.75mm_HandSolder
C6, C7: 1uF; C_0603_1608Metric_Pad1.05x0.95mm_HandSolder
C8, C9: 10uF; C_1210_3225Metric_Pad1.42x2.65mm_HandSolder
D1, D2: SCH; D_SOD-123
L1: 2.2uH; L_Coilcraft_XxL4040
L2: 3.3uH; L_Coilcraft_XxL4040
R1: 4.7k; R_0603_1608Metric_Pad1.05x0.95mm_HandSolder
R2: 8.2k; R_0603_1608Metric_Pad1.05x0.95mm_HandSolder
R3: 268k; R_0603_1608Metric_Pad1.05x0.95mm_HandSolder
R4: 158k; R_0603_1608Metric_Pad1.05x0.95mm_HandSolder
R5: 604k; R_0603_1608Metric_Pad1.05x0.95mm_HandSolder
R6: 1M; R_0603_1608Metric_Pad1.05x0.95mm_HandSolder
R7: 115k; R_0603_1608Metric_Pad1.05x0.95mm_HandSolder
R41: 150k; R_0603_1608Metric_Pad1.05x0.95mm_HandSolder
U1: ADP5071; TSSOP-20_4.4x6.5mm_P0.65mm

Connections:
/3V3: C1.1, C4.1, C5.1, U1.15 (PVIN1), U1.16 (PVINSYS), U1.17 (PVIN2); also elsewhere on the board
/GND: C1.2, C2.2, C3.2, C4.2, C5.2, C6.2, C7.1, C8.1, C9.1, L2.2, R3.2, R7.2, U1.2 (SYNC/FREQ), U1.13 (AGND), U1.19 (PGND); also elsewhere on the board
/Power Rail/5V_switched: C8.2, D1.2 (A), R5.2; also elsewhere on the board
/Power Rail/-5V_switched: C9.2, D2.1 (K), R41.2; also elsewhere on the board
unnamed: C2.1, R1.2
unnamed: C3.1, R2.2
unnamed: C6.1, U1.3 (SEQ), U1.4 (SLEW), U1.7 (EN1), U1.9 (EN2), U1.14 (VREG)
unnamed: C7.2, R4.2, U1.12 (VREF)
unnamed: D1.1 (K), L1.2, U1.20 (SW1)
unnamed: D2.2 (A), L2.1, U1.18 (SW2)
unnamed: L1.1, U1.1 (INBK)
unnamed: R1.1, U1.6 (COMP1)
unnamed: R2.1, U1.10 (COMP2)
unnamed: R3.1, U1.8 (SS)
unnamed: R4.1, R6.1, U1.11 (FB2)
unnamed: R5.1, R7.1, U1.5 (FB1)
unnamed: R6.2, R41.1

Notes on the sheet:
Analog Devices ADP5071 2A/1.2A DC -to-DC Switching Regulator Independent Positive and Negative Outputs
Rft1
Rfb1
Rft2
Rfb2
Cout1
Cout2
Cvref
Rc1
Rc2
Cc1
Cc2
Cvreg
Soft start resistor 268k => 4ms
Sequential enable mode SEQ = VREG EN2 = 1 EN1 = enable internal ref ahead of outputs
SYNC/FREQ low for 1.2MHz
SLEW to VREG for normal mode

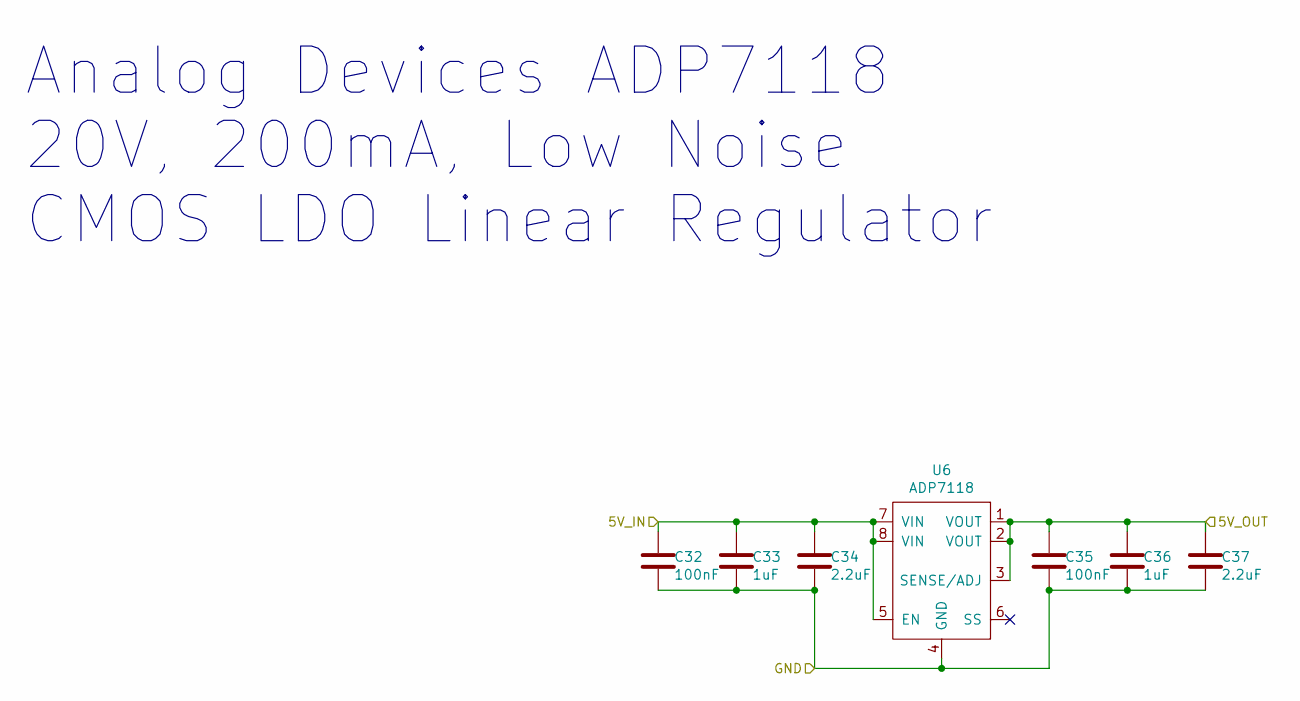
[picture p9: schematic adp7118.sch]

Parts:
C10, C13: 100nF; C_0603_1608Metric_Pad1.05x0.95mm_HandSolder
C11, C14: 1uF; C_0603_1608Metric_Pad1.05x0.95mm_HandSolder
C12, C15: 2.2uF; C_0603_1608Metric_Pad1.05x0.95mm_HandSolder
U2: ADP7118; SOIC-8_3.9x4.9mm_P1.27mm

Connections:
/5V0: C10.1, C11.1, C12.1, U2.5 (EN), U2.7 (VIN), U2.8 (VIN); also elsewhere on the board
/5V_CIRRUS: C13.1, C14.1, C15.1, U2.1 (VOUT), U2.2 (VOUT), U2.3 (SENSE/ADJ); also elsewhere on the board
/GND: C10.2, C11.2, C12.2, C13.2, C14.2, C15.2, U2.4 (GND); also elsewhere on the board

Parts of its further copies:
C26, C29, C32, C35: 100nF; C_0603_1608Metric_Pad1.05x0.95mm_HandSolder
C27, C30, C33, C36: 1uF; C_0603_1608Metric_Pad1.05x0.95mm_HandSolder
C28, C31, C34, C37: 2.2uF; C_0603_1608Metric_Pad1.05x0.95mm_HandSolder
U5, U6: ADP7118; SOIC-8_3.9x4.9mm_P1.27mm

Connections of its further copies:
/5V_ADC: C29.1, C30.1, C31.1, U5.1 (VOUT), U5.2 (VOUT), U5.3 (SENSE/ADJ); also elsewhere on the board
/5V_DAC: C35.1, C36.1, C37.1, U6.1 (VOUT), U6.2 (VOUT), U6.3 (SENSE/ADJ); also elsewhere on the board
/GND: C26.2, C27.2, C28.2, C29.2, C30.2, C31.2, C32.2, C33.2, C34.2, C35.2, C36.2, C37.2, U5.4 (GND), U6.4 (GND); also elsewhere on the board
/Power Rail/5V_switched: C26.1, C27.1, C28.1, C32.1, C33.1, C34.1, U5.5 (EN), U5.7 (VIN), U5.8 (VIN), U6.5 (EN), U6.7 (VIN), U6.8 (VIN); also elsewhere on the board

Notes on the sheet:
Analog Devices ADP7118 20V, 200mA, Low Noise CMOS LDO Linear Regulator

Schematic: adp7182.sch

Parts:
C16, C21: 100nF; C_0603_1608Metric_Pad1.05x0.95mm_HandSolder
C17, C20: 1nF; C_0603_1608Metric_Pad1.05x0.95mm_HandSolder
C18, C19: 2.2uF; CP_Elec_4x5.7
U3: ADP7182; SOT-23-5

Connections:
/-5V_ADC: C19.2, C20.1, C21.1, U3.5 (VOUT); also elsewhere on the board
/GND: C16.2, C17.2, C18.1, C19.1, C20.2, C21.2, U3.1 (GND); also elsewhere on the board
/Power Rail/-5V_switched: C16.1, C17.1, C18.2, U3.2 (VIN), U3.3 (EN); also elsewhere on the board

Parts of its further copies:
C38, C43: 100nF; C_0603_1608Metric_Pad1.05x0.95mm_HandSolder
C39, C42: 1nF; C_0603_1608Metric_Pad1.05x0.95mm_HandSolder
C40, C41: 2.2uF; CP_Elec_4x5.7
U7: ADP7182; SOT-23-5

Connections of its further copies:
/-5V_DAC: C41.2, C42.1, C43.1, U7.5 (VOUT); also elsewhere on the board
/GND: C38.2, C39.2, C40.1, C41.1, C42.2, C43.2, U7.1 (GND); also elsewhere on the board
/Power Rail/-5V_switched: C38.1, C39.1, C40.2, U7.2 (VIN), U7.3 (EN); also elsewhere on the board

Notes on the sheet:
Analog Devices ADP7182 –28 V, −200 mA, Low Noise,Linear Regulator

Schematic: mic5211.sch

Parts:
C22, C24, C25: 1uF; C_0603_1608Metric_Pad1.05x0.95mm_HandSolder
C23: 100nF; C_0603_1608Metric_Pad1.05x0.95mm_HandSolder
U4: MIC5211; SOT-23-6

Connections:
/3.3V_A: C24.1, U4.6 (VOUTA); also elsewhere on the board
/3.3V_B: C25.2, U4.4 (VOUTB); also elsewhere on the board
/3V3: C22.1, C23.1, U4.1 (EN_A), U4.3 (EN_B), U4.5 (VIN); also elsewhere on the board
/GND: C22.2, C23.2, C24.2, C25.1, U4.2 (GND); also elsewhere on the board

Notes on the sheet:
Dual μCap 80mA LDO Regulator

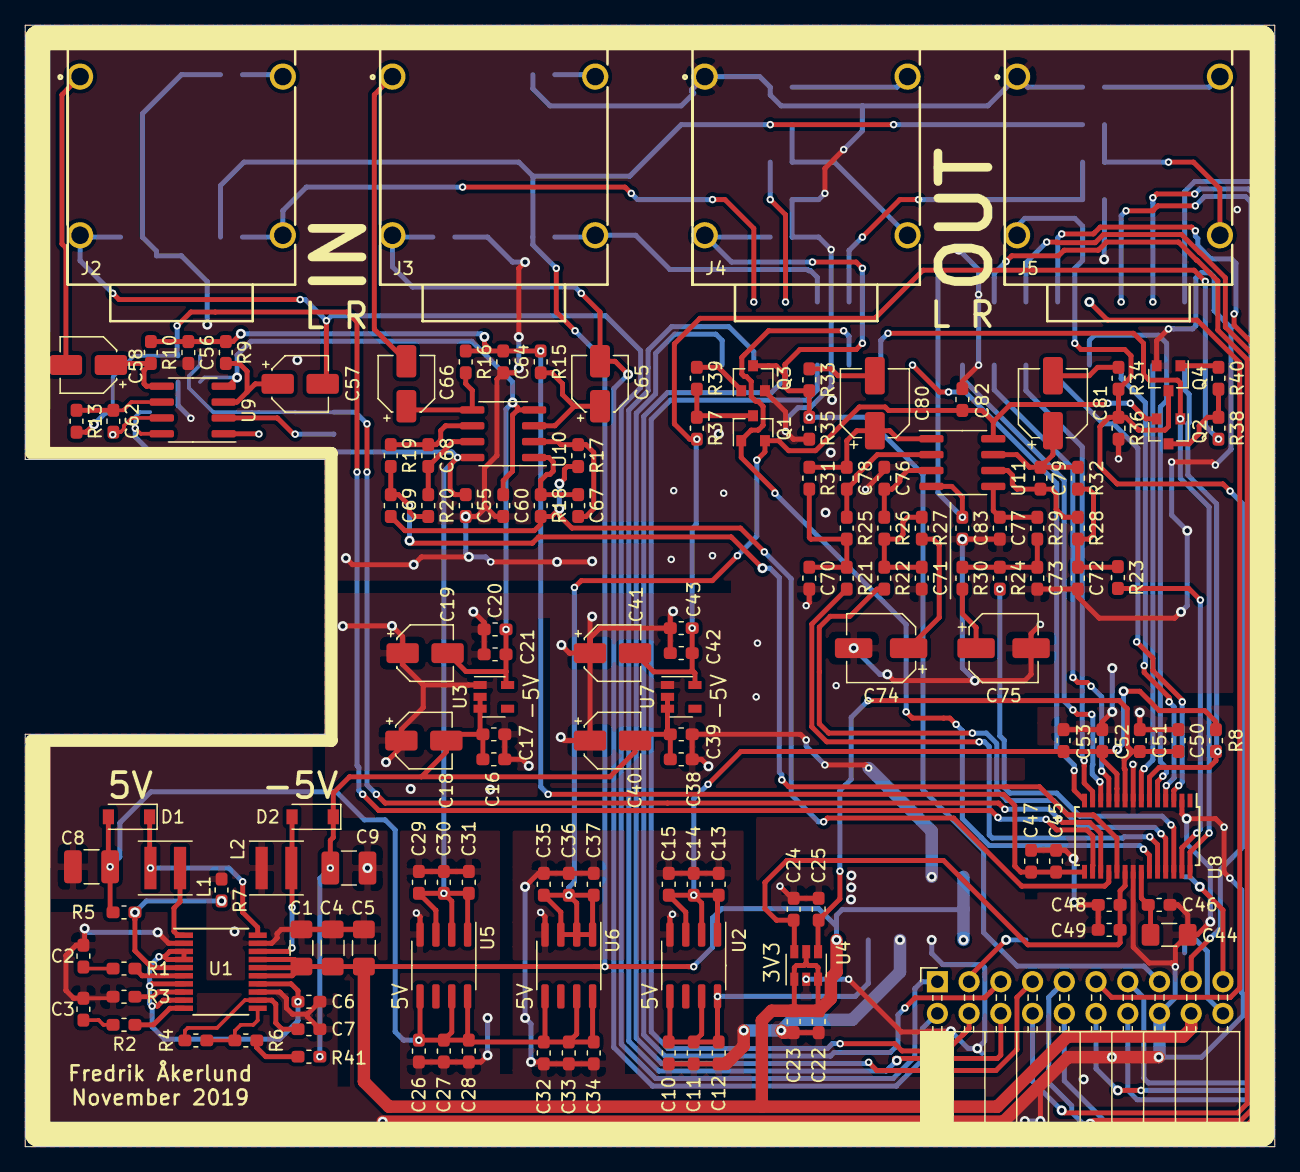
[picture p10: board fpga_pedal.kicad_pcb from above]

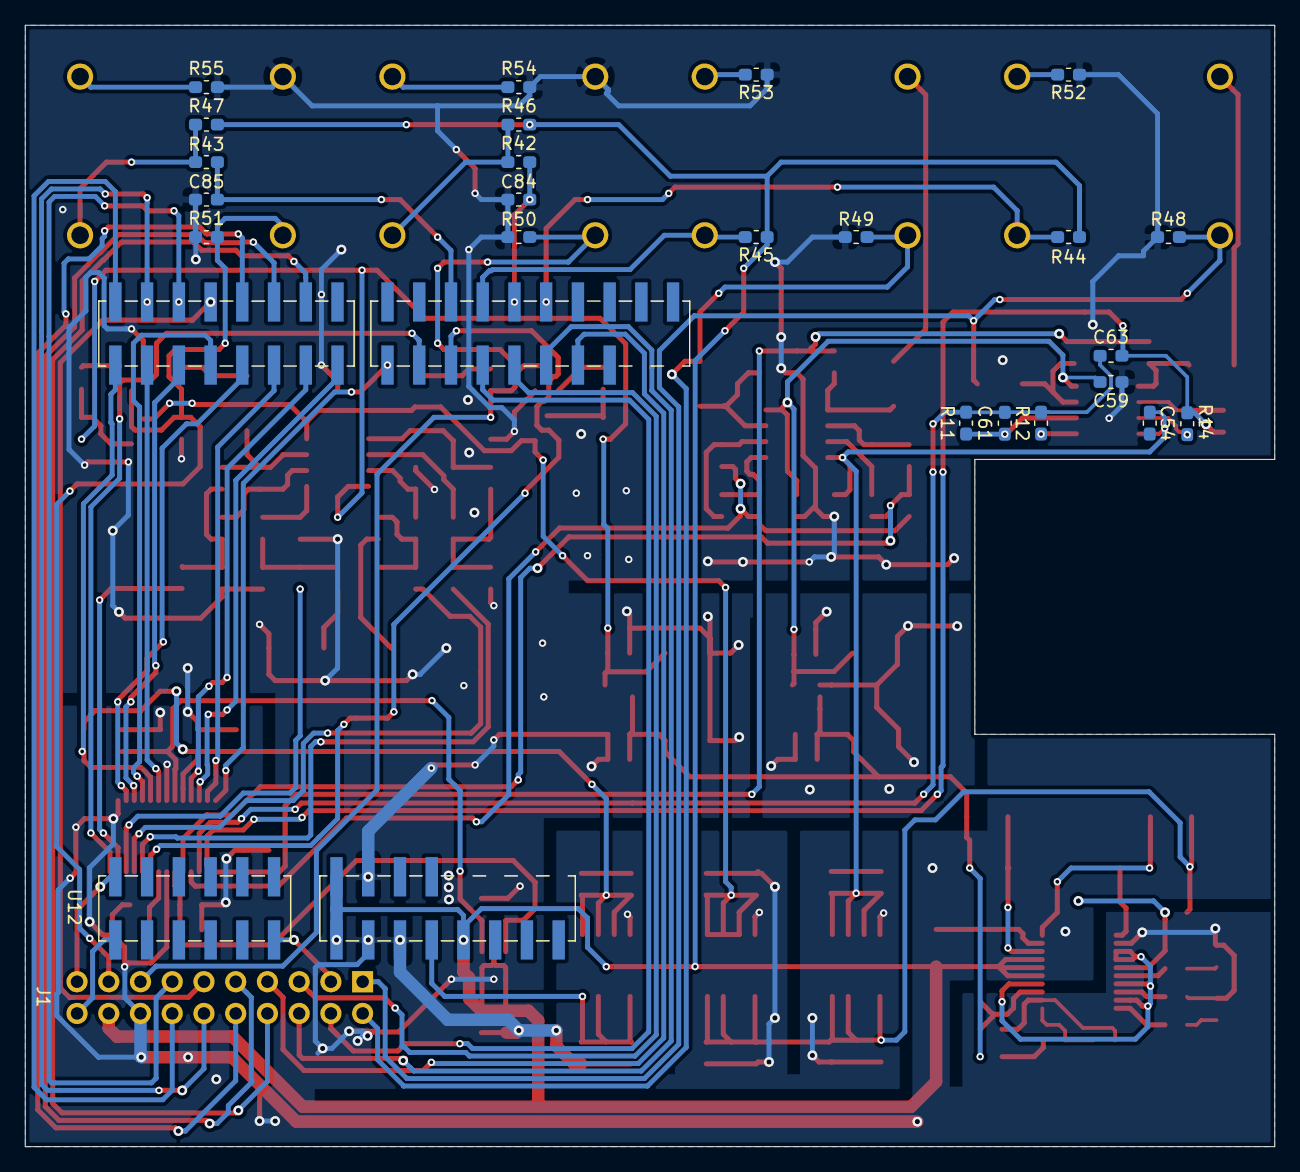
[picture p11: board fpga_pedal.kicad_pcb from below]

Board: 2 copper layers, 100.0 x 89.8 mm, 165 parts (23 on the bottom side), 106 nets.
